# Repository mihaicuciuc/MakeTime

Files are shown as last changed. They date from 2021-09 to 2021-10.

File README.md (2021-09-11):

# MakeTime
Arduino-compatible development platform whose primary function is a clock

# Description
MakeTime is a clock that uses a ring of 24 RGB LEDs to display time. Hours and minutes are displayed using different colors. As it uses just 24 LEDs, its granularity is 2.5 minutes. The time can be set using its single button, located in the center of the clock face.

MakeTime is also an Arduino-compatible development platform, and is designed with hacking in mind. In addition to the addressable LEDs, the button and the DS3231 RTC, makers can access many of the Arduino pins on an expansion header they can populate themselves.

# Hardware
[EasyEDA project](https://easyeda.com/mihai.cuciuc/clock_v2-0_copy_copy_copy_copy_copy_copy_copy_copy)

# Images
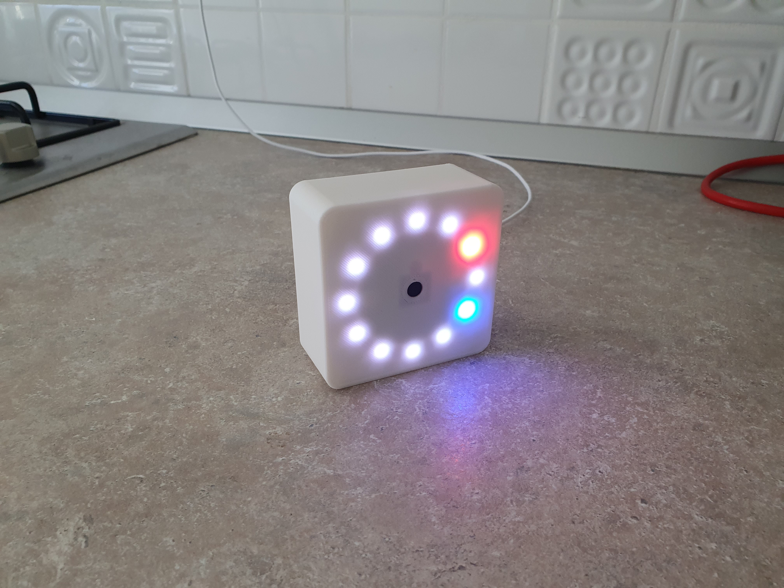
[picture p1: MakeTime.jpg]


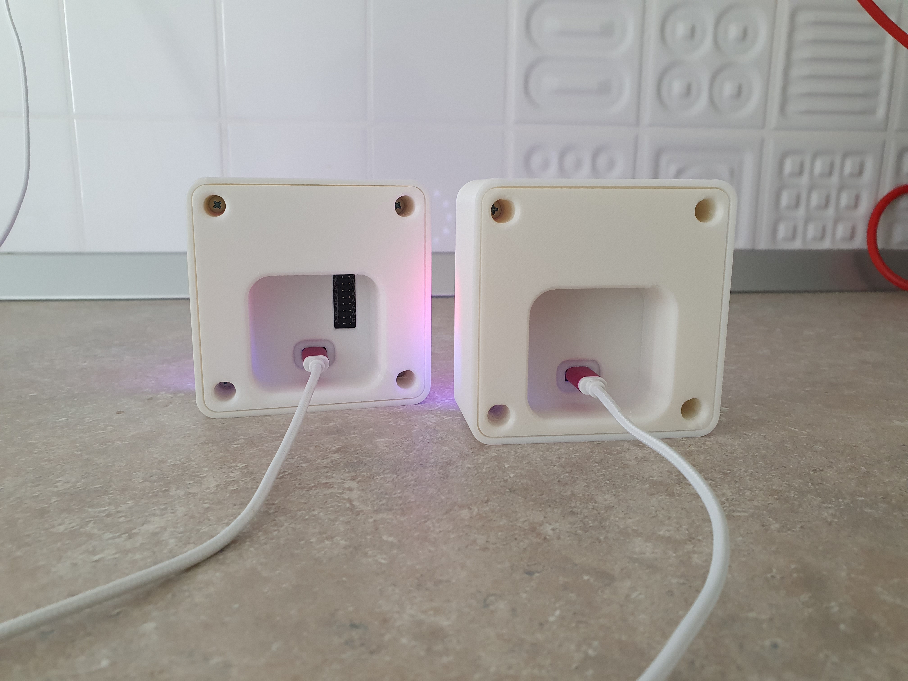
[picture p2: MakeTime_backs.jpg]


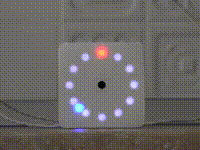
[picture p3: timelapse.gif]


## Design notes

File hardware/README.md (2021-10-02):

This version fixes the missing a 100nF cap between CH340 DTR# and MCU RESET pin.

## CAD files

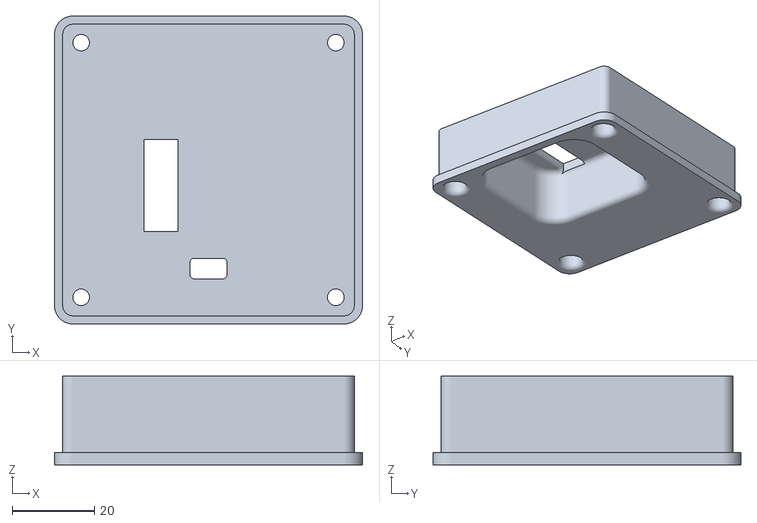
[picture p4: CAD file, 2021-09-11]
case/MakeTime-MakerBack.stl
75.0 x 75.0 x 21.6

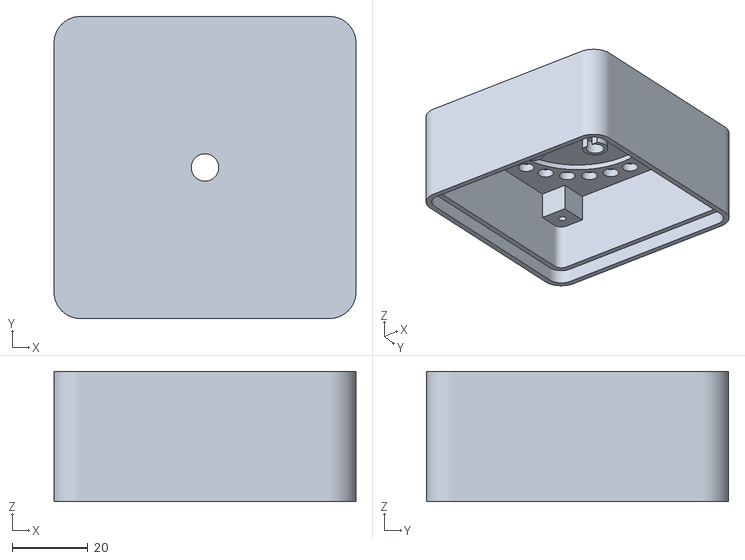
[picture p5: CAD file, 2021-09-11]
case/MakeTime-Case.stl
80.0 x 80.0 x 34.6

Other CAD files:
case/MakeTime.FCStd
case/MakeTime-Back.stl

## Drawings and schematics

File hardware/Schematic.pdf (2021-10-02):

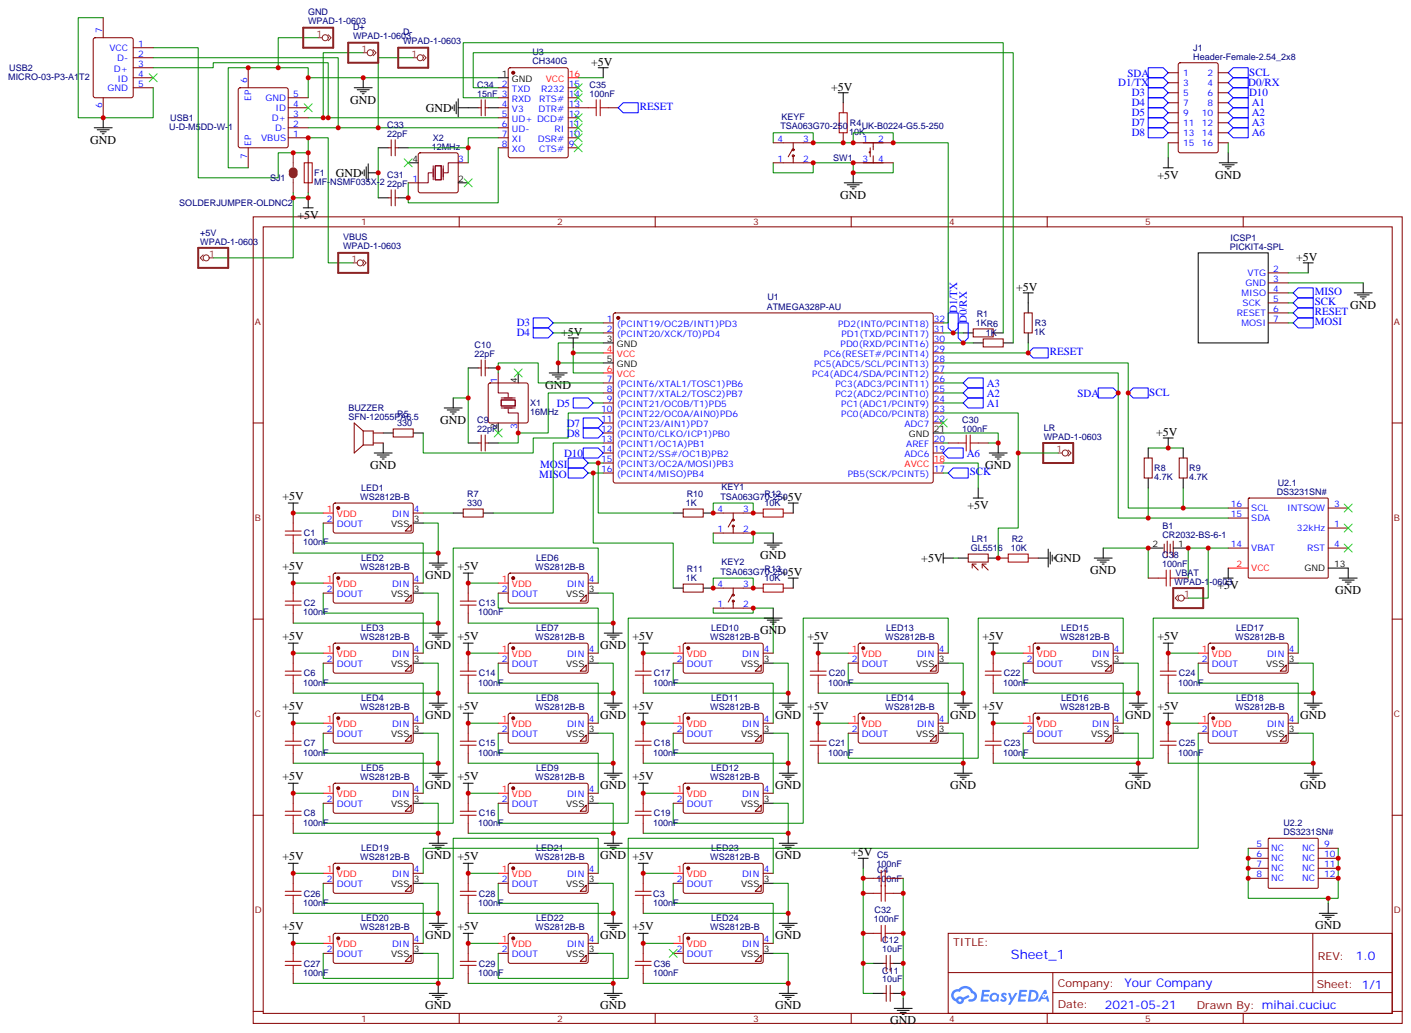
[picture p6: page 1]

DSR# 10 RI 11 DCD# 12 DTR# 13 RTS# 14 R232 15 VCC 16

Drawn By: mihai.cuciuc

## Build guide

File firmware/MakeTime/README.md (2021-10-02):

Fuse bits need to be programmed, toghether with the Arduino bootloader.
Extended: 0xFC
High: 0xDA
Low: 0xFF

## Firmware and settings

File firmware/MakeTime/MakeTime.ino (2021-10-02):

#include <EEPROM.h>
#include <Adafruit_NeoPixel.h>
#include <Wire.h>
#include <ds3231.h>

#ifdef __AVR__
 #include <avr/power.h> // Required for 16 MHz Adafruit Trinket
#endif

// Which pin on the Arduino is connected to the NeoPixels?
// On a Trinket or Gemma we suggest changing this to 1:
#define LED_PIN    9
#define BUZZER_PIN 6


// How many NeoPixels are attached to the Arduino?
#define LED_COUNT 24

// each color R, G, B
// Each map {colorH, colorM, colorFace1, colorFace2}
const uint8_t colorMapArray[][3][12] PROGMEM = {
// Map 0, Captain America
 {
  {10, 0, 0,    0, 0, 11,    3, 3, 4,   3, 3, 4},   // Low intensity
  {60, 0, 0,    0, 0, 60,    4, 5, 5,   4, 5, 5},   // Mid intensity
  {255, 0, 0,   0, 0, 255,   20, 20, 20,  20, 20, 20},   // High intensity
 },
// Map 1, Colours
 {
  {10, 10, 0,   0, 5, 15,    3, 3, 4,   2, 0, 0},   // Low intensity
  {70, 70, 0,   0, 42, 90,   6, 7, 7,   6, 0, 0},   // Mid intensity
  {255, 255, 0, 0, 160, 255, 20, 20, 20, 20, 0, 0},   // High intensity
 },
// Map 2, Joker Old
 {
  {13, 0, 0,    0, 12, 0,    3, 3, 4,   2, 0, 2},   // Low intensity
  {60, 0, 0,    0, 60, 0,    6, 7, 7,   4, 0, 6},   // Mid intensity
  {255, 0, 0,    0, 255, 0,    20, 20, 20,   10, 0, 20},   // High intensity
 },
// Map 3, Joker New
 {
  {13, 0, 0,    0, 0, 17,    3, 3, 0,   2, 2, 0},   // Low intensity
  {60, 0, 0,    0, 0, 60,    7, 7, 0,   9, 4, 0},   // Mid intensity
  {255, 0, 0,    0, 0, 255,    20, 20, 0,   22, 13, 0},   // High intensity
 },
// Map 4, Dr Strange
 {
  {8, 8, 0,     0, 0, 16,    2, 0, 0,   2, 0, 0},   // Low intensity
  {30, 30, 0,   0, 0, 60,    5, 0, 0,   5, 0, 0},   // Mid intensity
  {130, 130, 0,   0, 0, 255,    20, 0, 0,   20, 0, 0},   // High intensity
 },
// Map 5, Purple love
 {
  {0, 10, 17,   12, 0, 18,    2, 0, 4,   2, 0, 4},   // Low intensity
  {0, 20, 40,   25, 0, 40,    4, 0, 8,   4, 0, 8},   // Mid intensity
  {0, 80, 200,  70, 0, 255,    10, 0, 20,   10, 0, 20},   // High intensity
 },
// Map 6, Crystal blue
 {
  {12, 12, 0,     0, 13, 13,      0, 3, 2,   0, 3, 2},   // Low intensity
  {25, 25, 0,   0, 36, 36,    0, 5, 4,   0, 5, 4},   // Mid intensity
  {255, 255, 0,   0, 255, 255,    0, 20, 20,   0, 20, 20},   // High intensity
 },
// Map 7, Cool blue
 {
  {7, 8, 7,      0, 0, 14,    0, 0, 2,   0, 0, 2},   // Low intensity
  {17, 17, 17,   0, 0, 70,    0, 0, 9,   0, 0, 9},   // Mid intensity
  {70, 70, 70,   0, 0, 255,    0, 0, 20,   0, 0, 20},   // High intensity
 },
// Map 8, Firy red
 {
  {11, 10, 0,   14, 0, 0,    2, 0, 0,   2, 0, 0},   // Low intensity
  {40, 30, 0,   50, 0, 0,    9, 0, 0,   9, 0, 0},   // Mid intensity
  {160, 100, 0,   255, 0, 0,    20, 0, 0,   20, 0, 0},   // High intensity
 },
// Map 9, Emerald green
 {
  {0, 6, 6,     0, 8, 0,     0, 2, 0,   0, 2, 0},   // Low intensity
  {0, 25, 25,   0, 40, 0,    0, 9, 0,   0, 9, 0},   // Mid intensity
  {0, 70, 70,   0, 255, 0,    0, 20, 0,   0, 20, 0},   // High intensity
 },
// Map 10, Yellow submarine
 {
  {6, 13, 0,    14, 16, 0,    3, 3, 0,   3, 3, 0},   // Low intensity
  {25, 55, 0,   25, 25, 0,    5, 5, 0,   5, 5, 0},   // Mid intensity
  {70, 255, 0,   100, 100, 0,    20, 20, 0,   20, 20, 0},   // High intensity
 },
// Map 11, Cheshire Cat
 {
  {0, 5, 10,    0, 10, 0,    3, 3, 4,   0, 0, 0},   // Low intensity
  {0, 20, 40,   0, 50, 0,    9, 9, 9,   0, 0, 0},   // Mid intensity
  {0, 50, 160,   0, 255, 0,   20, 20, 20,   0, 0, 0},   // High intensity
 },
// Map 12, Dali
 {
  {6, 6, 0,     0, 6, 6,      0, 0, 0,   0, 0, 0},   // Low intensity
  {25, 25, 0,   0, 25, 25,    0, 0, 0,   0, 0, 0},   // Mid intensity
  {255, 255, 0,   0, 255, 255,    0, 0, 0,   0, 0, 0},   // High intensity
 },
};


ts t; //ts is a struct findable in ds3231.h
uint32_t color;
uint32_t colorH[3], colorM[3], colorFace1[3], colorFace2[3];
uint16_t adcVal = 0, adcThr[2];
uint8_t colorMap = 0, colorIdx = 0, ledOffset = 0;
uint8_t state = 0;
uint8_t i;

Adafruit_NeoPixel strip(LED_COUNT, LED_PIN, NEO_GRB + NEO_KHZ800);

void(* reset) (void) = 0;

void setup()
{
#if defined(__AVR_ATtiny85__) && (F_CPU == 16000000)
  clock_prescale_set(clock_div_1);
#endif

  pinMode(2, INPUT);
  digitalWrite(2, HIGH);
  
  strip.begin();           // INITIALIZE NeoPixel strip object (REQUIRED)
  strip.show();            // Turn OFF all pixels ASAP

  Wire.begin(); //start i2c (required for connection)
  DS3231_init(DS3231_INTCN); //register the ds3231 (DS3231_INTCN is the default address of ds3231, this is set by macro for no performance loss)

  if (EEPROM.read(0) != 0x00)
  {
    // New chip. Set up factory defaults
    factoryDefaults();
  }
  adcThr[0] = EEPROM.read(1);
  adcThr[1] = EEPROM.read(2);
  ledOffset = EEPROM.read(3);
  colorMap = EEPROM.read(4);

  readColorMap(colorMap);

  colorIdx = 0;
}

void factoryDefaults()
{
    EEPROM.write(1, 0x09);  // Low brightness threshold
    EEPROM.write(2, 0x11);  // Mid brightness threshold
    EEPROM.write(3, 0);  // LED ring orientation
    EEPROM.write(4, 0x00);  // Color map
    EEPROM.write(0, 0x00);  // configured flag
    reset();
}

void readColorMap(uint8_t m)
{
  for (i = 0; i < 3; i++)
  {
    colorH[i] = strip.Color(pgm_read_byte(&colorMapArray[m][i][0]), pgm_read_byte(&colorMapArray[m][i][1]), pgm_read_byte(&colorMapArray[m][i][2]));
    colorM[i] = strip.Color(pgm_read_byte(&colorMapArray[m][i][3]), pgm_read_byte(&colorMapArray[m][i][4]), pgm_read_byte(&colorMapArray[m][i][5]));
    colorFace1[i] = strip.Color(pgm_read_byte(&colorMapArray[m][i][6]), pgm_read_byte(&colorMapArray[m][i][7]), pgm_read_byte(&colorMapArray[m][i][8]));
    colorFace2[i] = strip.Color(pgm_read_byte(&colorMapArray[m][i][9]), pgm_read_byte(&colorMapArray[m][i][10]), pgm_read_byte(&colorMapArray[m][i][11]));
  }
}

void loop()
{
  static unsigned long buttonTimeStamp = 0, buttonFallingEdge = 0, buttonLen = 0;
  static uint8_t buttonState = 1;
  static uint8_t buttonPressed = 0;
  static uint8_t oldState;

  adcVal = analogRead(A0) / 40;
  if (adcVal < adcThr[0])
  {
    colorIdx = 0;
  }

  // Histeresis implemented through truncation. When adcVal == adcThr[0] do nothing. This happens for 40 ADC counts.
  if ((adcVal > adcThr[0]) && (adcVal < adcThr[1]))
  {
    colorIdx = 1;
  }

  if (adcVal > adcThr[1])
  {
    colorIdx = 2;
  }

  if ((digitalRead(2) == 0) && (buttonState == 1))
  {
    // Button falling edge
    buttonTimeStamp = millis();
    buttonFallingEdge = buttonTimeStamp;
    buttonState = 0;
  }

  oldState = state;
  
  if ((digitalRead(2) == 1) && (buttonState == 0))
  {
    // Button rising edge
    buttonTimeStamp = millis();
    buttonLen = buttonTimeStamp - buttonFallingEdge;
    buttonState = 1;
    
    if (buttonLen > 10000)
    {
      // very long press
      tone(BUZZER_PIN, 1000);
      delay(750);
      noTone(BUZZER_PIN);
      factoryDefaults();
    }
    else if (buttonLen > 1000)
    {
      // long press
      tone(BUZZER_PIN, 1000);
      delay(200);
      noTone(BUZZER_PIN);
      state++;
    }
    else if (buttonLen > 50)
    {
      // short press
      tone(BUZZER_PIN, 1000);
      delay(50);
      noTone(BUZZER_PIN);
      buttonPressed = 1;
    }
  }

  if (state > 3)
  {
    state = 0;
  }

  if ((millis() - buttonTimeStamp) >= 5000)
  {
    state = 0;
  }

  if (oldState != state)
  {
    // Handle state transition actions here.
    if (3 == oldState) EEPROM.write(4, colorMap);
    if (0 == state) showAnimation();
  }

  switch (state)
  {
    case 0:    // default clock run state
      if (buttonPressed == 1) showAnimation();
      runClock();
      break;
    case 1:
      runSetH(buttonPressed);
      break;
    case 2:
      runSetM(buttonPressed);
      break;
    case 3:
      runSetColorMap(buttonPressed);
      break;
   }

  buttonPressed = 0;
}


void runSetColorMap(uint8_t buttonPressed)
{
  if (buttonPressed != 0)
  {
    colorMap++;
    colorMap %= sizeof(colorMapArray) / (sizeof(uint8_t)*3*12);
    readColorMap(colorMap);
  }
  
  strip.clear();
  setColor(2, colorM[colorIdx]);
  setColor(3, colorM[colorIdx]);
  setColor(4, colorM[colorIdx]);

  setColor(20, colorH[colorIdx]);
  setColor(21, colorH[colorIdx]);
  setColor(22, colorH[colorIdx]);

  setColor(6, colorFace1[colorIdx]);
  setColor(12, colorFace1[colorIdx]);
  setColor(18, colorFace1[colorIdx]);

  setColor(8, colorFace2[colorIdx]);
  setColor(10, colorFace2[colorIdx]);
  setColor(14, colorFace2[colorIdx]);
  setColor(16, colorFace2[colorIdx]);
  strip.show();
}



void runSetH(uint8_t buttonPressed)
{
  DS3231_get(&t);
  t.hour += buttonPressed;
  if (t.hour > 23) t.hour = 0;
  DS3231_set(t);

  strip.clear();
  // draw clock face
  setColor(0, colorFace1[colorIdx]);
  setColor(12, colorFace1[colorIdx]);
  setColor((t.hour % 12) * 2, colorH[colorIdx]);
  strip.show();
}

void runSetM(uint8_t buttonPressed)
{
  uint8_t ledM;
  
  DS3231_get(&t);
  if (buttonPressed != 0)
  {
    t.min += 1;
    if (t.min > 59) t.min = 0;
    t.sec = 0;
    DS3231_set(t);
  }

  ledM = (t.min / 10) * 4;
  
  strip.clear();
  // draw clock face
  setColor(0, colorFace1[colorIdx]);
  setColor(6, colorFace1[colorIdx]);
  setColor(12, colorFace1[colorIdx]);
  setColor(18, colorFace1[colorIdx]);
  setColor(ledM, colorM[colorIdx]);
  for (i = 0; i < (t.min % 10); i++)
  {
    setColor((ledM + i + 1) % 24, colorFace2[colorIdx]);
  }
  strip.show();
}

void runClock()
{
  static unsigned long lastRefresh = 0;
  static uint8_t displayCounter = 0;
  static uint8_t old_ledM = 0;
  static uint8_t ledH = 0, ledM = 0;

  if ((millis() - lastRefresh) >= 500)
  {
    lastRefresh = millis();

    DS3231_get(&t);
    ledH = (t.hour % 12) * 2;
    ledM = ((uint16_t)t.min*60 + t.sec)/150;  // 3600 / 24 = 250

    strip.clear();
    showClock(ledH, ledM);
    strip.show();
  }
}

void showClock(uint8_t ledH, uint8_t ledM)
{
  // draw clock face  
  setColor(0, colorFace1[colorIdx]);
  setColor(6, colorFace1[colorIdx]);
  setColor(12, colorFace1[colorIdx]);
  setColor(18, colorFace1[colorIdx]);

  setColor(2, colorFace2[colorIdx]);
  setColor(4, colorFace2[colorIdx]);
  setColor(8, colorFace2[colorIdx]);
  setColor(10, colorFace2[colorIdx]);
  setColor(14, colorFace2[colorIdx]);
  setColor(16, colorFace2[colorIdx]);
  setColor(20, colorFace2[colorIdx]);
  setColor(22, colorFace2[colorIdx]);

  setColor(ledH, colorH[colorIdx]);        

  if (ledM == ledH) setColor(ledM, colorH[colorIdx] + colorM[colorIdx]);
  else setColor(ledM, colorM[colorIdx]);
}

void showAnimation()
{
  // draw eyes
  for (i = 0; i < 3; i++)
  {
    strip.clear();
    strip.show();
    delay(50);
    
    setColor(21, colorM[colorIdx]);
    setColor(3, colorM[colorIdx]);
    strip.show();
    delay(1000);
  }

  // draw smile
  for (i = 16; i > 7; i--)
  {
    setColor(i, colorH[colorIdx]);   
    strip.show();
    delay(100);
  }

  delay(1500);

  // wink
  for (i = 0; i < 2; i++)
  {
    setColor(3, 0);
    strip.show();
    delay(300);
    setColor(3, colorM[colorIdx]);
    strip.show();
    delay(1000);
  }
  
}

void setColor(uint8_t pixel, uint32_t color)
{
  strip.setPixelColor((pixel + ledOffset) % 24, color);
}

uint32_t getColor(uint8_t pixel)
{
  strip.getPixelColor((pixel + ledOffset) % 24);
}

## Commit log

2021-10-02 Fixed missing 100nF cap on MCU reset line
    Also added footprints for 2 extra buttons on back of PCB
2021-10-02 Simplified user interface
    Removed option to rotate display as current case design is only fit for one orientation.
    Removed selectable brightness thresholds as they were very unintuitive to set. Can be set in factoryDefaults() function.
